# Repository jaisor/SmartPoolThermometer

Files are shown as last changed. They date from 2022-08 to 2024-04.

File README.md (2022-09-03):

# Smart Pool Thermometer

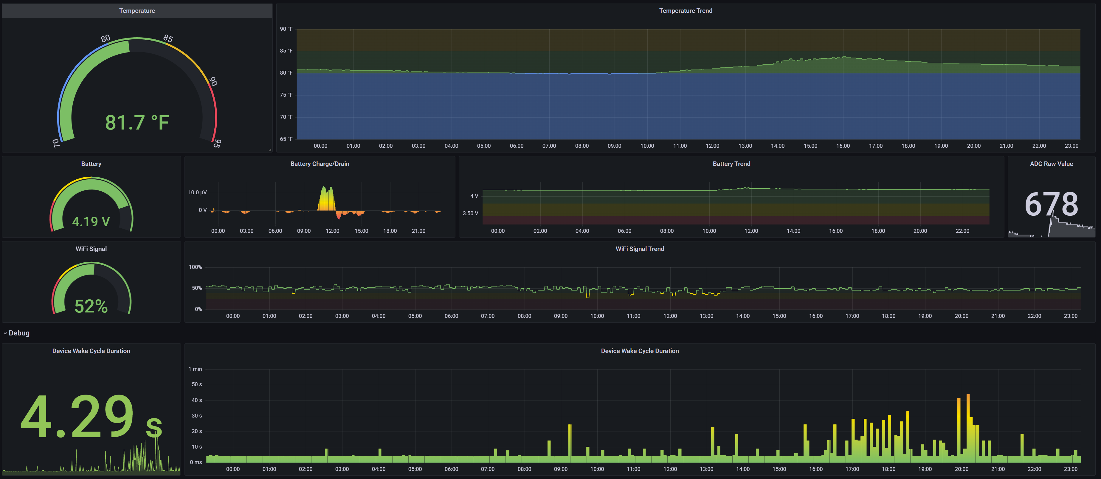
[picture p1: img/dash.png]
Dash

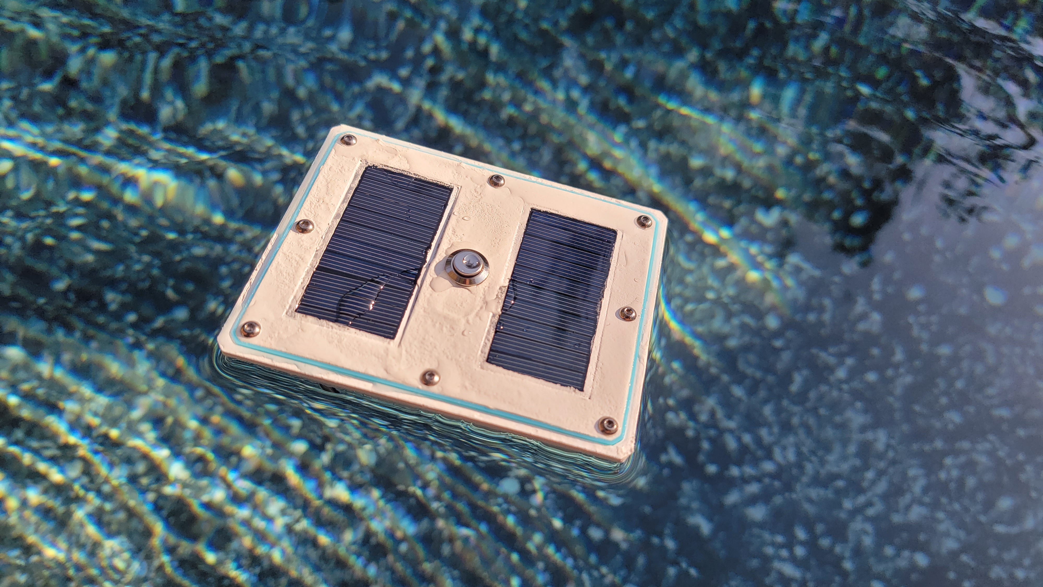
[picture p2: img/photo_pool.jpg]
PoolPhoto


## Requirements

* Floating water-tight pool sensor
* Temperature and other telemetry (internal battery voltage) readings submitted over Wifi via MQTT at reasonable intervals (~5min)
* Low power consumption, battery powered with solar recharge during the day 
* Device initial configuration via self-hosted AP (`ESP8266ST_XXXXX` / `password123`) / IP (`192.168.4.1`)
* Device resets to (factory) defaults by 3 power-cycles within 2 seconds of boot
* Device configurable over MQTT and capable of OTA firmware updates
* Data visualization - MQTT - Prometheus - Grafana dashboard

## Notes

Code is compatible with both ESP8266 and ESP32 boards, but ESP8266 draws significantly less power (4mA) during deep sleep

## Sensor

### ESP8266 / ESP32 Development

USB driver for Windows required: [Silicon Labs CP210X](https://www.silabs.com/developers/usb-to-uart-bridge-vcp-drivers)

Recommended: [VSCode](https://code.visualstudio.com/) + [PlatformIO](https://platformio.org/)

### Bill of materials (BOM)

* [ESP8266 ESP-12](https://www.amazon.com/gp/product/B081PX9YFV)
* [DS18B20 Temperature Sensor Waterproof](https://www.amazon.com/dp/B012C597T0)
* [JST 3 Pin Connector](https://www.amazon.com/dp/B01DUC1PW6)
* [2x 10K Resistors; 1x 1K Resistor](https://www.amazon.com/dp/B08FD1XVL6)
* [6x 5V 60mA Epoxy Solar Panel](https://www.amazon.com/dp/B0736W4HK1)
* [18650 Battery Clip Holder](https://www.amazon.com/dp/B0721Y3NDQ)
* [JST Connectors](https://www.amazon.com/dp/B071XN7C43)
* [TP4056 Battery Charger Module](https://www.amazon.com/dp/B098989NRZ)
* [Prototype board (optional)](https://www.amazon.com/dp/B00FXHXT80)
* [M3 3D Printing Brass Nuts, 5mm x 6mm](https://www.amazon.com/dp/B09KZSJS88)
* [M3 6mm Button](https://www.amazon.com/dp/B083HCLFM1)

### Schematic 

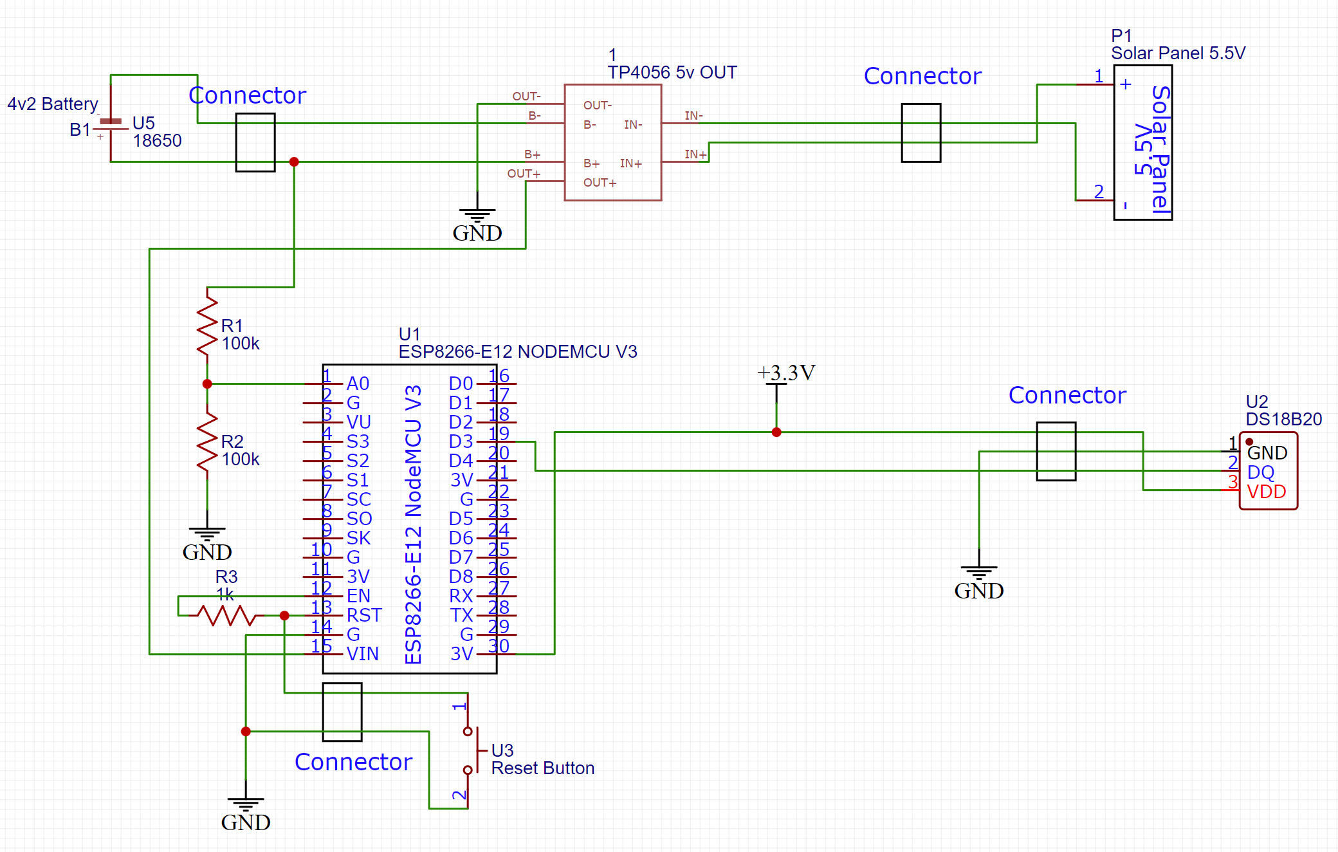
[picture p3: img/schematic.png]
Schematic

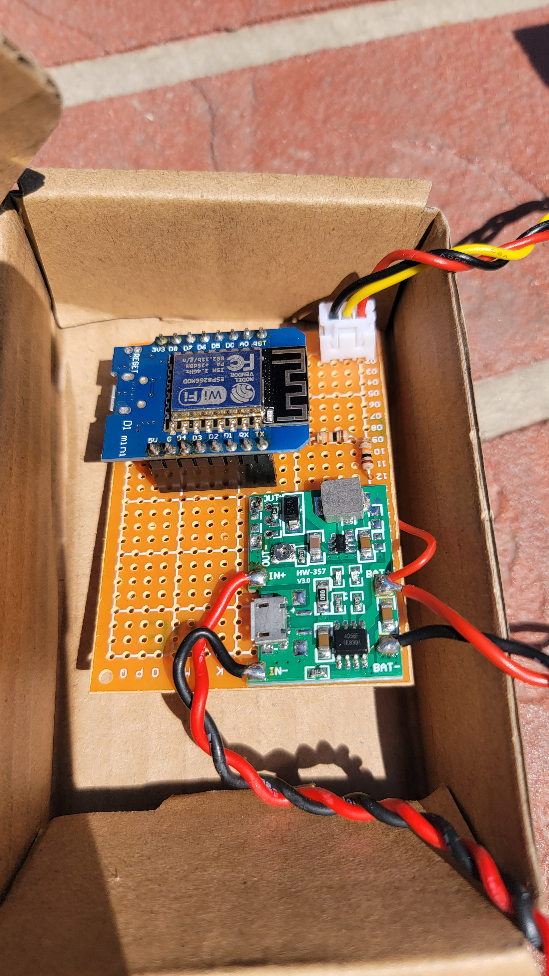
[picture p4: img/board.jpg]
Board


### Enclosure 

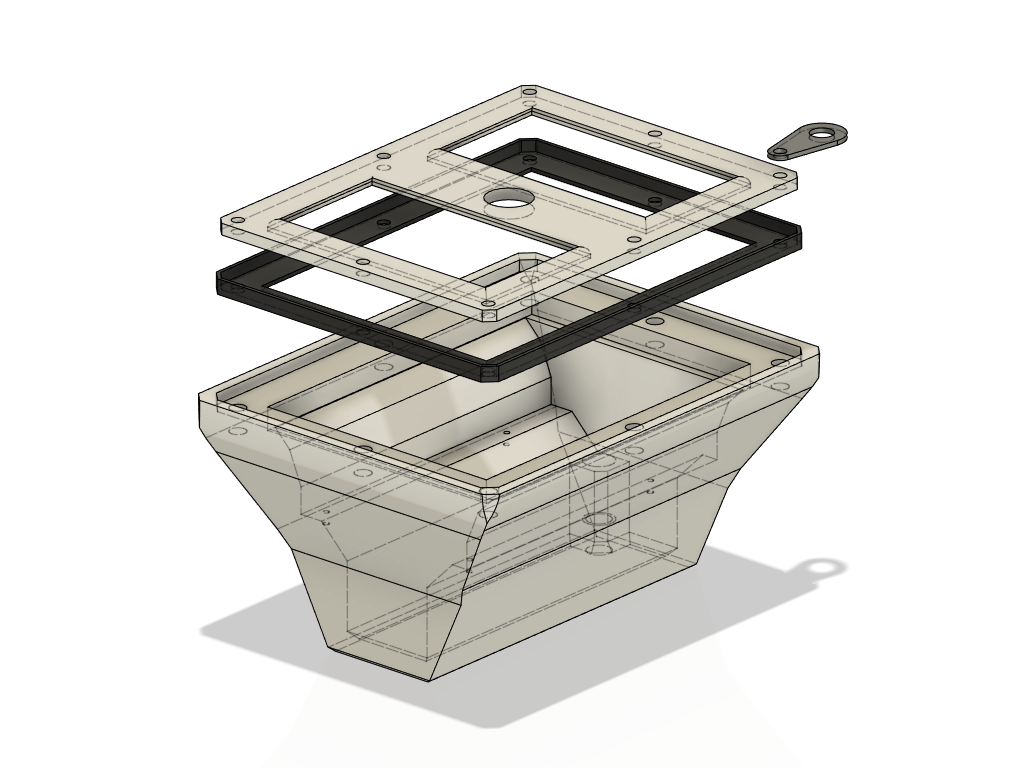
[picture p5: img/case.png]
Case


All parts print without support in the default orientation.

* [Box](stl/box.stl) - White PETG or something UV and heat resistant. 4 walls and top/bottom layers. 10-30% infill should be enough.
* [Lid](stl/lid.stl) - White PETG or something UV and heat resistant. 100% Infill
* [Gasket](stl/gasket.stl) - TPU or something flesible to act as a gasket. 100% Infill
* [AnchorLoop](stl/anchor.stl) - TPU, optional, can be used to tie the thermometer in the sunny side of the pool if needed.

### Build & Assembly

First - drop a brass knurled insert in each of the box bolt holes. The inserts can be driven into the plastic easily with a soldering iron. Make sure they are fairly flush with the surface. Do not lower too much as to compromise the outer wall.
Close the threads with throw-away set of bolts during the next phase of waterproofing.

#### Waterproofing

Below was my process for the several prototypes I made and the final version. It might be overkill, but I have not experienced a single water leak after weeks in the pool.

1. Coat the box with ... epoxy like coating. Heavier on the bottom and sides of the box. Very light on the top and the lid as to not compromise dimensional fit. Wipe any excess around the top and lid if concerned, when this stuff hardens it is very difficult to correct (sanding and headaches). Mask off the inside of the box where the board and battery will go.
2. Insert the thermometer sensor in the box and mask it off with tape about 10mm away from the box. Glue without any gaps and apply some silicone on the top side when the glue is dry. Wait for the silicone to dry/cure.
3. Glue the solar panes, ensure no gaps on the back side. Mask off with tape the effecive area of the solar panel.
4. Spray (rubber coating), thicker on the bottom and around the unmasked part of the sensor, thinner on top and on the lid to ensure the parts fit snuggly but still fit.

#### Circuit board layout 

* Ensure the output of the TP4056 board goingto the ESP8266 is 5v with the little adjuster provided

#### Assembly

Battery and case go on the bottom. The temp sensor in the designate hole pushed all the way down and sealed with appropriate waterproof sealer / adhesive.
The solar panels should be glued and then water proof sealed too.
The linked prototype board fits inside well and can be screwed with some 1mm screws or glued or taped down.

## Data visualization

Useful articles and guides:
* https://frederic-hemberger.de/notes/prometheus/monitoring-temperature-and-humidity-with-mqtt/
* https://grafana.com/docs/grafana/latest/setup-grafana/configure-docker/
* https://grafana.com/docs/grafana-cloud/quickstart/docker-compose-linux/

The following instructions are better suited for a "local" install - desktop, raspberry pi, server on LAN. Deployments expected to communicate over public internet should use appropriate encryption and authentication configuration. Large-scale deployments might also want to leverage a docker-compose, Terraform, etc. 

### MQTT broker

```
docker run -dit \
    --name=mqtt-mac \
    --restart=unless-stopped \
    -p 1883:1883 \
    -v "$APPROPRIATE_VAR_PATH/mosquitto:/mosquitto" \
    eclipse-mosquitto:latest
```

### MQTT JSON exporter

Subscribes to a topic, parses JSON received from that topic and populates Prometheus with the compatible JSON values.
https://github.com/tg44/mqtt-prometheus-message-exporter

```
docker run -dit --restart unless-stopped -p 9324:9000 --name mqtt_json \
    -v "$APPROPRIATE_VAR_PATH/mqtt_json:/data" \
    -e CONF_PATH=/data/exporter.conf \
    ghcr.io/tg44/mqtt-prometheus-message-exporter:latest
```

### MQTT REST API for Alexa

```
docker run -dit --restart unless-stopped -p 3443:3443 \
  -e MQTT_SERVER="$MQTT_SERVER" \
  -e MQTT_TOPIC="$MQTT_TOPIC" \
  -e HTTPS_PRIVATE_KEY_PATH="$PATH_TO_KEY" \
  -e HTTPS_CERTIFICATE_PATH="$PATH_TO_CERT" \
  -e API_KEY="$API_KEY" \
  jaisor/mqtt-rest-api:latest
```

### Prometehus

`prometheus/config.yml`

```
scrape_configs:

# Prometehus itself
  - job_name: 'prometheus'
    scrape_interval: 30s
    static_configs:
      - targets: ['localhost:9090']

# MQTT exporter
  - job_name: 'mqtt'
    scrape_interval: 30s
    static_configs:
    - targets: ['<HOSTNAME>.local:9344']
```

```
docker run -dit --restart unless-stopped -p 9090:9090 \
    --name prometheus-mac \
    -v "$APPROPRIATE_VAR_PATH/prometheus:/data" \
    prom/prometheus:latest \
    --config.file="/data/config.yml" \
    --storage.tsdb.path="/data/prometheus"
```

### Grafana

```
docker run -dit --restart unless-stopped -p "3000:3000" --name grafana-mac grafana/grafana:latest
```

### Dashboard

Dash

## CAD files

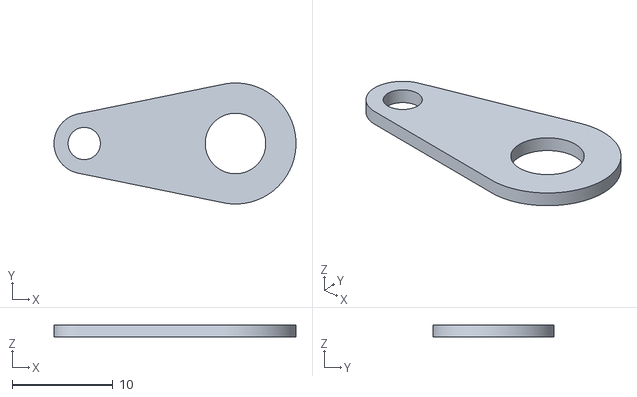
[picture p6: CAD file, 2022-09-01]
stl/anchor.stl
24.0 x 12.0 x 1.20

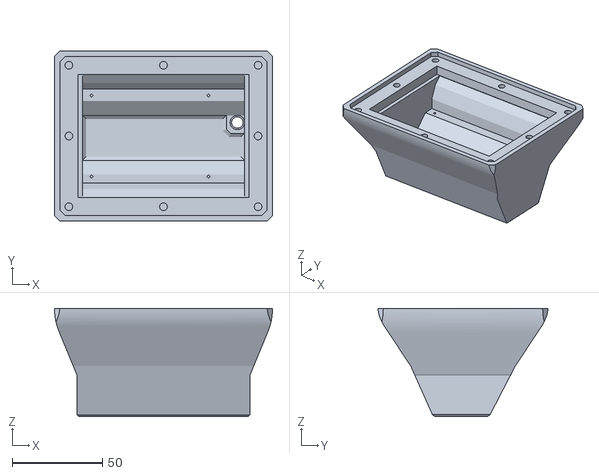
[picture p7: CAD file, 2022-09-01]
stl/box.stl
121.0 x 94.5 x 60.0

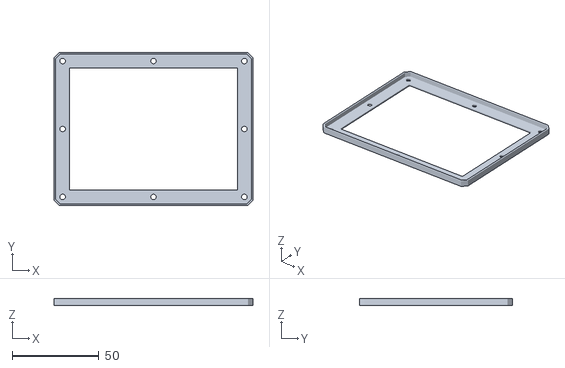
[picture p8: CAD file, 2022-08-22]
stl/gasket.stl
115.0 x 88.5 x 4.00

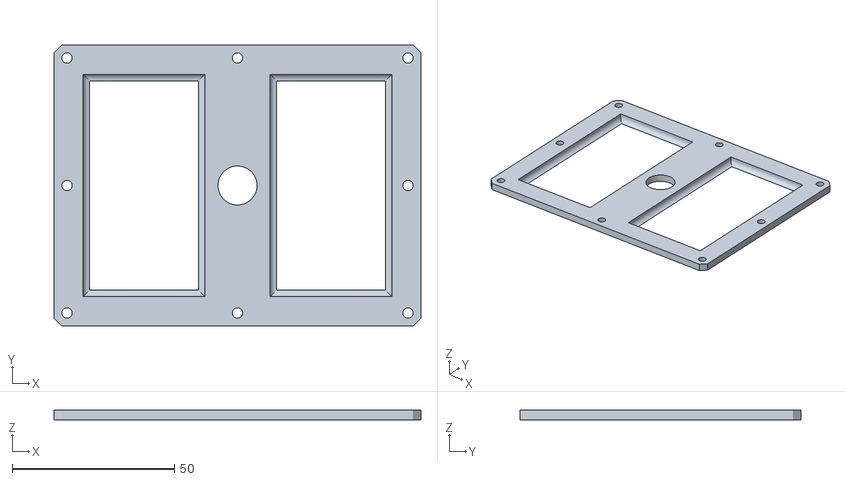
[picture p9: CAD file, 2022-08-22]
stl/lid.stl
113.0 x 86.5 x 3.00

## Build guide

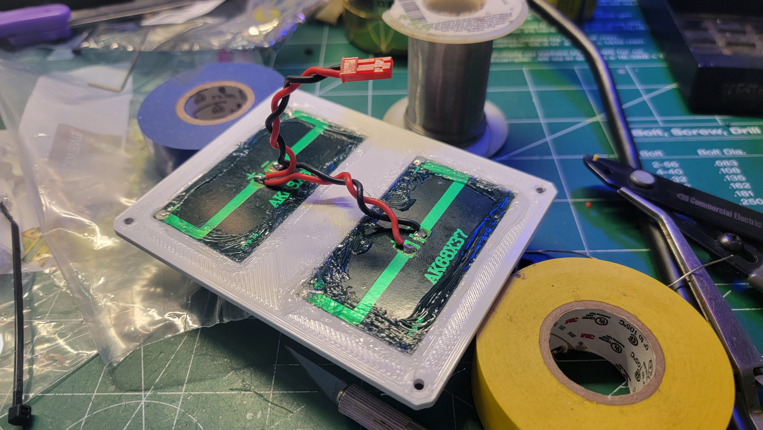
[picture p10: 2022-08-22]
img/lid_assembly.jpg

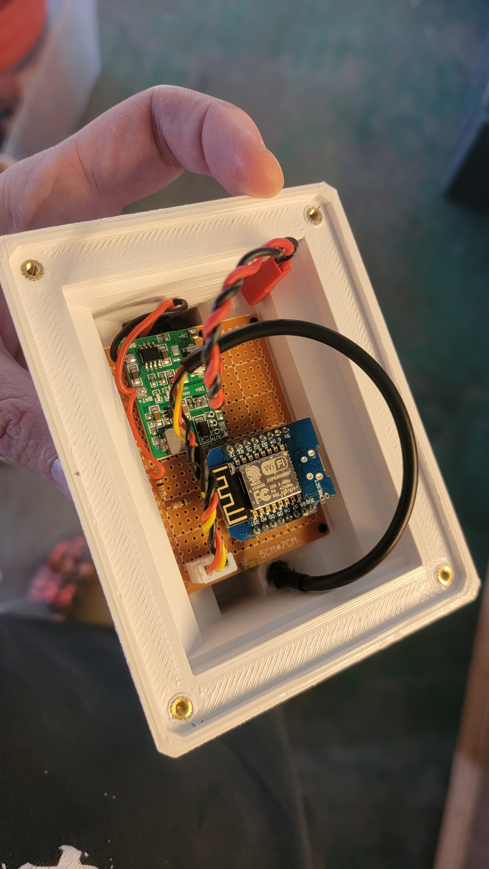
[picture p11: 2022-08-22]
img/box_assembly.jpg

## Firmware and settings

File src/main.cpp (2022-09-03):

#include <Arduino.h>
#include <functional>
#include <ArduinoLog.h>

#if !( defined(ESP32) ) && !( defined(ESP8266) )
  #error This code is intended to run on ESP8266 platform! Please check your Tools->Board setting.
#endif

#include "wifi/WifiManager.h"
#include "Device.h"

#ifdef ESP32
#elif ESP8266
  ADC_MODE(ADC_TOUT);
#endif

CWifiManager *wifiManager;
CDevice *device;

unsigned long tsSmoothBoot;
bool smoothBoot;
unsigned long tsMillisBooted;

void setup() {
  Serial.begin(115200);  while (!Serial); delay(200);
  randomSeed(analogRead(0));

  //Log.begin(LOG_LEVEL_VERBOSE, &Serial);
  Log.begin(LOG_LEVEL_NOTICE, &Serial);
  Log.noticeln("Initializing...");  

  pinMode(INTERNAL_LED_PIN, OUTPUT);
  #ifdef ESP32
    digitalWrite(INTERNAL_LED_PIN, HIGH);
  #elif ESP8266
    digitalWrite(INTERNAL_LED_PIN, LOW);
  #endif
  

#ifdef LED_PIN_BOARD
  digitalWrite(LED_PIN_BOARD, HIGH);
#endif

  if (EEPROM_initAndCheckFactoryReset() >= 3) {
    Log.warningln("Factory reset conditions met!");
    EEPROM_wipe();  
  }

  tsSmoothBoot = millis();
  smoothBoot = false;

  EEPROM_loadConfig();

  device = new CDevice();
  wifiManager = new CWifiManager(device);

  Log.infoln("Initialized");
}

void loop() {
  
  if (!smoothBoot && millis() - tsSmoothBoot > FACTORY_RESET_CLEAR_TIMER_MS) {
    smoothBoot = true;
    EEPROM_clearFactoryReset();
    tsMillisBooted = millis();
    Log.noticeln("Device booted smoothly!");
  }

  device->loop();
  wifiManager->loop();

  if (wifiManager->isRebootNeeded()) {
    return;
  }
  
  // Conditions for deep sleep:
  // - Min time elapsed since smooth boot (to catch up on any MQTT messages)
  // - Smooth boot
  // - Wifi not in AP mode
  // - Succesfully submitted 1 sensor reading over MQTT
  if (smoothBoot 
    && configuration.deepSleepDurationSec > 0 
    && millis() - tsMillisBooted > DEEP_SLEEP_MIN_AWAKE_MS
    && wifiManager->isJobDone() ) {
    delay(100);
    Log.noticeln("Initiating deep sleep for %u usec", configuration.deepSleepDurationSec );
    #ifdef ESP32
      digitalWrite(INTERNAL_LED_PIN, LOW);
      ESP.deepSleep((uint64_t)configuration.deepSleepDurationSec * 1e6);
    #elif ESP8266
      digitalWrite(INTERNAL_LED_PIN, HIGH);
      ESP.deepSleep((uint64_t)configuration.deepSleepDurationSec * 1e6); 
    #endif
  }

  if (configuration.deepSleepDurationSec > 0 && device->getUptime() > configuration.deepSleepDurationSec * 1000) {
    Log.noticeln("Device is not sleeping right, resetting to save battery");
    #ifdef ESP32
      ESP.restart();
    #elif ESP8266
      ESP.reset();
    #endif
  }
  
  delay(200);
  yield();
}

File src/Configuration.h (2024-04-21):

#pragma once

#include <Arduino.h>
#include <functional>
#include <ArduinoLog.h>

#define WIFI    // 2.4Ghz wifi access point
//#define LED     // Individually addressible LED strip
//#define KEYPAD    // Buttons

#define EEPROM_FACTORY_RESET 0       // Byte to be used for factory reset device fails to start or is rebooted within 1 sec 3 consequitive times
#define EEPROM_CONFIGURATION_START 1   // First EEPROM byte to be used for storing the configuration

#define FACTORY_RESET_CLEAR_TIMER_MS 2000   // Clear factory reset counter when elapsed, considered smooth boot

#ifdef ESP32
  #define DEVICE_NAME "ESP32ST"
#elif ESP8266
  #define DEVICE_NAME "ESP8266ST"
#endif

#ifdef WIFI
  #define WIFI_SSID DEVICE_NAME
  #define WIFI_PASS "password123"

  // If unable to connect, it will create a soft accesspoint
  #define WIFI_FALLBACK_SSID DEVICE_NAME // device chip id will be suffixed
  #define WIFI_FALLBACK_PASS "password123"

  #define NTP_SERVER "pool.ntp.org"
  #define NTP_GMT_OFFSET_SEC -25200
  #define NTP_DAYLIGHT_OFFSET_SEC 0

  // Web server
  #define WEB_SERVER_PORT 80
#endif

#ifdef LED
  #define LED_CHANGE_MODE_SEC   60
  #ifdef ESP32
    #define LED_PIN 12
  #elif ESP8266
    #define LED_PIN 2
  #endif
  #define LED_STRIP_SIZE 240  // 267 for RingLight, 240 for PingPong table light
  #define LED_BRIGHTNESS 0.1  // 0-1, 1-max brightness, make sure your LEDs are powered accordingly
  #define LED_TYPE WS2812B
  #define LED_COLOR_ORDER GRB
#endif

#define TEMP_UNIT_CELSIUS     0
#define TEMP_UNIT_FAHRENHEIT  1
//#define TEMP_SENSOR_DS18B20
//#define TEMP_SENSOR_BME280
//#define TEMP_SENSOR_DHT
#define TEMP_SENSOR_AHT
#ifdef ESP32
  #define TEMP_SENSOR_PIN 0
#elif ESP8266
  #define TEMP_SENSOR_PIN D3
#endif
#ifdef TEMP_SENSOR_DHT
  #define TEMP_SENSOR_DHT_TYPE    DHT22
#endif

#define BATTERY_SENSOR  // ADC A0 using 0-3.3v voltage divider
#ifdef BATTERY_SENSOR
  #define BATTERY_SENSOR_ADC_PIN  A0
#endif

#define INTERNAL_LED_PIN LED_BUILTIN

#define DEEP_SLEEP_INTERVAL_SEC 300 // 5 min
#define BATTERY_VOLTS_DIVIDER 162.3 // 162.3 - LiPo 1cell max 4.2v; 45.2 - Pb auto max 14.8v
#define DEEP_SLEEP_MIN_AWAKE_MS 5000 // Minimum time to remain awake after smooth boot

#define MQTT_DATA_JSON  0
#define MQTT_DATA_SCALAR  1
#define MQTT_DATA_BOTH  2

struct configuration_t {

  #ifdef WIFI
    char wifiSsid[32];
    char wifiPassword[63];
    
    // ntp
    char ntpServer[128];
    long gmtOffset_sec;
    int daylightOffset_sec;

    // mqtt
    char mqttServer[128];
    uint16_t mqttPort;
    char mqttTopic[128];
    uint16_t mqttDataType; // 0-json(one message); 1-scalar(multiple messages); 2-both; 
  #endif

  #ifdef LED
    float ledBrightness;
    uint8_t ledMode;
    unsigned long ledDelayMs;
    unsigned long ledCycleModeMs;
    uint16_t ledStripSize;
  #endif

  char name[128];
  float battVoltsDivider;
  uint16_t deepSleepDurationSec; // 0 - deep sleep disabled, stay awake
  uint8_t tempUnit;

  char _loaded[7]; // used to check if EEPROM was correctly set
  
};

extern configuration_t configuration;

uint8_t EEPROM_initAndCheckFactoryReset();
void EEPROM_clearFactoryReset();

void EEPROM_saveConfig();
void EEPROM_loadConfig();
void EEPROM_wipe();

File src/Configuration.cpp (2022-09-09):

#include <Arduino.h>
#include <EEPROM.h>
#include "Configuration.h"

configuration_t configuration;

uint8_t EEPROM_initAndCheckFactoryReset() {
  Log.noticeln("Configuration size: %i", sizeof(configuration_t));
  
  EEPROM.begin(sizeof(configuration_t) + EEPROM_FACTORY_RESET + 1);
  uint8_t resetCounter = EEPROM.read(EEPROM_FACTORY_RESET);

  Log.noticeln("Factory reset counter: %i", resetCounter);
  Log.noticeln("EEPROM length: %i", EEPROM.length());

  // Bump reset counter
  EEPROM.write(EEPROM_FACTORY_RESET, resetCounter + 1);
  EEPROM.commit();

  return resetCounter;
}

void EEPROM_clearFactoryReset() {
  EEPROM.write(EEPROM_FACTORY_RESET, 0);
  EEPROM.commit();
}

void EEPROM_saveConfig() {
  Log.infoln("Saving configuration to EEPROM");
  EEPROM.put(EEPROM_CONFIGURATION_START, configuration);
  EEPROM.commit();
}

void EEPROM_loadConfig() {

  configuration = {};
  EEPROM.get(EEPROM_CONFIGURATION_START, configuration);

  Log.noticeln("Configuration loaded: %s", configuration._loaded);

  if (strcmp(configuration._loaded, "jaisor")) {
    // blank
    Log.infoln("Blank configuration, loading defaults");
    strcpy(configuration._loaded, "jaisor");
    strcpy(configuration.name, DEVICE_NAME);
    #ifdef LED
      configuration.ledBrightness = LED_BRIGHTNESS;
      strcpy(configuration.ntpServer, NTP_SERVER);
      configuration.gmtOffset_sec = NTP_GMT_OFFSET_SEC;
      configuration.daylightOffset_sec = NTP_DAYLIGHT_OFFSET_SEC;
      configuration.ledMode = 0;
      configuration.ledCycleModeMs = LED_CHANGE_MODE_SEC * 1000;
      configuration.ledDelayMs = 10;
      configuration.ledBrightness = LED_BRIGHTNESS;
      configuration.ledStripSize = LED_STRIP_SIZE;
    #endif
    #ifdef WIFI
      strcpy(configuration.ntpServer, NTP_SERVER);
      configuration.gmtOffset_sec = NTP_GMT_OFFSET_SEC;
      configuration.daylightOffset_sec = NTP_DAYLIGHT_OFFSET_SEC;
      strcpy(configuration.mqttServer, "");
      configuration.mqttPort = 1883;
      strcpy(configuration.mqttTopic, "");
      configuration.mqttDataType = MQTT_DATA_JSON;
    #endif

    configuration.battVoltsDivider = BATTERY_VOLTS_DIVIDER;
    configuration.deepSleepDurationSec = DEEP_SLEEP_INTERVAL_SEC;
    configuration.tempUnit = TEMP_UNIT_CELSIUS;

    EEPROM_saveConfig();
  }

#ifdef LED
  if (isnan(configuration.ledBrightness)) {
    Log.verboseln("NaN brightness");
    configuration.ledBrightness = LED_BRIGHTNESS;
  }
  if (isnan(configuration.ledMode)) {
    Log.verboseln("NaN ledMode");
    configuration.ledMode = 0;
  }
  if (isnan(configuration.ledCycleModeMs)) {
    Log.verboseln("NaN ledCycleModeMs");
    configuration.ledCycleModeMs = 0;
  }
  if (isnan(configuration.ledDelayMs)) {
    Log.verboseln("NaN ledDelayMs");
    configuration.ledDelayMs = 10;
  }
  if (isnan(configuration.ledStripSize)) {
    Log.verboseln("NaN ledStripSize");
    configuration.ledStripSize = LED_STRIP_SIZE;
  }
#endif

#ifdef WIFI
  String wifiStr = String(configuration.wifiSsid);
  for (auto i : wifiStr) {
    if (!isAscii(i)) {
      Log.verboseln("Bad SSID, loading default: %s", wifiStr.c_str());
      strcpy(configuration.wifiSsid, "");
      break;
    }
  }
#endif

  Log.noticeln("Device name: %s", configuration.name);

  // FIXME: Always default NTP values
  strcpy(configuration.ntpServer, NTP_SERVER);
  configuration.gmtOffset_sec = NTP_GMT_OFFSET_SEC;
  configuration.daylightOffset_sec = NTP_DAYLIGHT_OFFSET_SEC;
}

void EEPROM_wipe() {
  Log.warningln("Wiping configuration with size %i!", EEPROM.length());
  for (uint16_t i = 0; i < EEPROM.length() ; i++) {
    EEPROM.write(i, 0);
  }
  EEPROM.commit();
}

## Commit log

2022-08-09 ESP only sensor
    [Configuration.h]
2022-08-10 Temp sensor working
2022-08-10 working MQTT push
    [Configuration.h]
2022-08-11 working temp on a different pin and mqtt
    [Configuration.h]
2022-08-12 Pretty much code complete
    [Configuration.h]
2022-08-13 minor tweaks
    [Configuration.h]
2022-08-13 jordan forgot
    [Configuration.h]
2022-08-14 fixed compatibility with ESP32
    [Configuration.h]
2022-08-14 pushing raw ADC value over MQTT. Changed to D3 for temp sensor as it is internally pulled up and save a resistor.
    [Configuration.h]
2022-08-14 schematic, and work on ReadMe
2022-08-15 work on readme
    [Configuration.h]
2022-08-20 stability improvements, reporting uptime to mqtt
    [Device.cpp, WifiManager.cpp, main.cpp]
2022-08-22 sleep fixes and more debugging
    [gasket.stl, lid.stl]
2022-08-23 work on config over MQTT
    [Configuration.h]
2022-08-23 supports config changes over MQTT
    [Configuration.h]
2022-08-31 Alexa skill and HTTP API for it, more work on ReadMe
    [anchor.stl, box.stl]
2022-09-02 code cleanup, added data type and temp unit
    [Configuration.h]
2022-09-09 support for DHT sensors
    [Configuration.h]
2022-09-13 Improved DHT sensor delays and stability
    [Device.cpp, WifiManager.cpp]
2023-12-22 improved wifi connection manager
    [Configuration.h]
2023-12-27 fixed voltage divider float
    [Configuration.h]
2024-04-21 lib update and support for AHT20 sensors
    [Configuration.h]
